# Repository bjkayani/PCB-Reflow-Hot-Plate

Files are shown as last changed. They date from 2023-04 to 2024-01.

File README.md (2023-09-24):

# PCB Reflow Hot Plate

The PCB Reflow Hot Plate is a temperature controlled 120 x 70 mm hot plate designed to reflow solder SMD circuit boards. This project was started due to a gap in the commercial solutions for a mid sized form factor hot plate. 

This project is a work in progress and various elements of it are continually improving and changing. Refer to the build guide for more information including a compatibility table. 

<br>

</a>

<br>

## Features

- 120x70mm (4.7x2.7in) aluminum hot plate
- 300 Watt PTC heating element
- ESP32-C3 based control board
- Tuned PID controller with configurable parameters
- Reflow mode with customizable reflow profiles
- Constant temeprature (heat) mode
- Upto 260 C temperature allows lead free reflow
- Easy to use GUI using 0.96" OLED display and 3 buttons
- Serial debugging over USB to monitor temperature
- Single power cable required for operation

<br>

## Design

### The main design considerations were:
- Atleast 70x70mm reflow area (the Miniware is 30x30mm)
- Slim design to allow tweezer manipulation with hands resting on the desk
- Commercially viable solution with a long operating life
- Easy to operature and minimal setup process
- Safe operation with multiple layers of safety

With these considerations in mind, this is the design I came up with. It uses an off the shelf heating plate with an embedded 300W heating element. I designed my own control board that includes everything needed to control the heating plate and can run entirely from mains input. 

I went with a small 0.96" OLED display and three buttons as that seems adequate to control the UI. The UI is simple and intuitive yet provides all the functionality needed to operate and customize the hot plate. 

Its all packaged in a slim, rectangular 3D printed case that exposes the hot plate provide a window for the display and integrated buttons. The hotplate has insulation placed underneath it to prevent heat loss from the bottom. The case needs to be printed in a relatively temperature resistant material to avoid warping at high temperature. 

</a>

<br>

## PCB

The PCB is designed in KiCAD. Its a 2-layer design and it contains everything needed to run the hot plate with a single mains input. The USB-C port provides power to the DC section and allows for programming the ESP32-C3 microcontroller. The OLED display is on a separate daughter board and mounted using M2 standoffs. A standard 0.96" OLED display module should work although there is some variation in the models avaiable. More information regarding that coming soon. 

### Version 1.1:

- [BOM](PCB/pcb-reflow-hot-plate/bom/pcb-reflow-hot-plate_1.2.html)
- [Gerber](PCB/pcb-reflow-hot-plate/output/pcb-reflow-hot-plate_Rev1.2.zip)

### Revision History

- Rev 1.0
    - Initial design
- Rev 1.1
    - AC-DC converter changed to HLK-5M05
    - SSR changed to popular OMRON compatible footprint
    - OLED display module moved to center align with buttons
    - SSR supply changed to +5V
    - AC in connector mounting peg holes increased in size
    - Minor silk screen updates
- Rev 1.2
    - AC in connector mounting holes further widened
    - OLED module footprint changed for newer modules
    - Tactile switches changed to 4.5x4.5x5mm
    - Neopixel added
    - Stemma QT connector added
    - SMD buzzer changed to SMD
    - AC fuse added
- Rev 1.3
    - RGB LED moved down
    - Heater and thermocouple connector rotated
    - Thermocouple GND line grounded

</a>
</a>

<br>

## Code

The code is written in Arduino IDE due to its ease of use and simlicity over PlatformIO and native ESP SDK. The code is split up into multiple files with each file containing functions relating to specific funcionality. 

The code is continually under development and I am adding new features regularly. I have also commented the code so that its easy to understand. Feel free to look through the code, file an issue if you encounter one or request features to be added. 

I have a lot of features I want to add that are on the road map but I first wanted to get the basic funtionality working and tested. These are listed at the start of the [main program file](Code/pcb-reflow-hot-plate/pcb-reflow-hot-plate.ino). 

<br>

## CAD

The housing is designed in SolidWorks. Its designed as a two part enclosure with a tab and screws to hold the two together. The heating plate comes with silicon feet that fit into the base. The base is raised to be slighly protruding from the top surface and insulation is put underneath to avoid heat dissipation from the bottom. 

The latest STL and design files can be found in the CAD folder. The assembly is missing the PCB due to import issues from KiCAD into SolidWorks.

</a>
</a>

<br>

## Build Guide

### Build guide is coming soon ...

### Compatibility Table

| PCB (HW) | OLED Module | Code (FW) | CAD |
| :---: | :---: | :---: | :---: |
| Rev 1.0 | SSD1306 0.96" 25.2x26mm <br> [AliExpress Link](https://www.aliexpress.us/item/2251832644208699.html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) | 1.0 | Housing Top v1 <br> Housing Base v1 |
| Rev 1.1 |  SSD1306 0.96" 27.6x27.6mm <br> [Amazon Link](https://amzn.to/43KL0ey) | 1.0  | Housing Top v2 <br> Housing Base v1 |
| Rev 1.2 |  SSD1306 0.96" 27.6x27.6mm <br> [Amazon Link](https://amzn.to/43KL0ey) | 1.1 |Housing Top v3 <br> Housing Base v2 <br> Light Pipe v1 |
| Rev 1.3 |  SSD1306 0.96" 27.6x27.6mm <br> [Amazon Link](https://amzn.to/43KL0ey) | 1.1 | Housing Top v3 <br> Housing Base v2 <br> Light Pipe v2 |

<br>

## Future Ideas
- [ ] Add mounting holes and pogo pin body connectors for accessories such as cooling fan, external temperature probe, fume extractor
- [ ] Make display separate from main PCB and shrink the main PCB
- [ ] Move the buttons to the bottom of the display
- [ ] Increase the size of the display to ~1.5in
- [ ] Switch to DC heater with thinner hot plate and USB-C PD (100 Watts)
- [ ] Switch to a square heating element
- [ ] Add integrated active cooling that blows air parallel to the hot plate
- [ ] Add multiple sensing options (thermocouple, thermistor etc.)
- [x] Add AC protection fuse
- [ ] Protection for reverse wired thermocouple

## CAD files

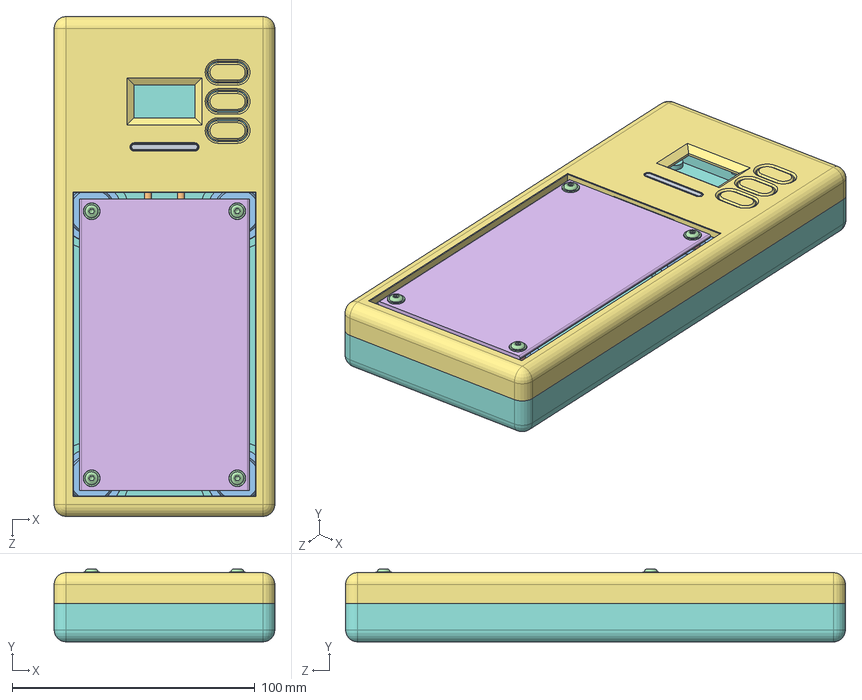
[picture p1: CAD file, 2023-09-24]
CAD/PCB Reflow Hot Plate Assembly.SLDASM
91.0 x 30.0 x 206.0 mm
Housing Base
Housing Top
hot-plate-120x70
M3-standoff x 4
97654A673_18-8 Stainless Steel Flanged Button Head Screw x 4
silicon-feet x 4
heating-element
light pipe

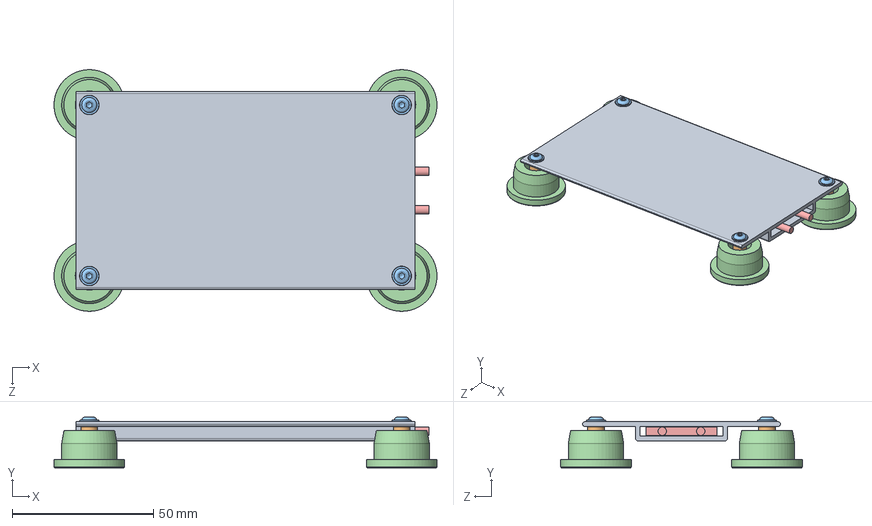
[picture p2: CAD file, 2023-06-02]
CAD/hot-plate-120x70-assembly.SLDASM
135.5 x 18.0 x 85.5 mm
hot-plate-120x70
M3-standoff x 4
97654A673_18-8 Stainless Steel Flanged Button Head Screw x 4
silicon-feet x 4
heating-element

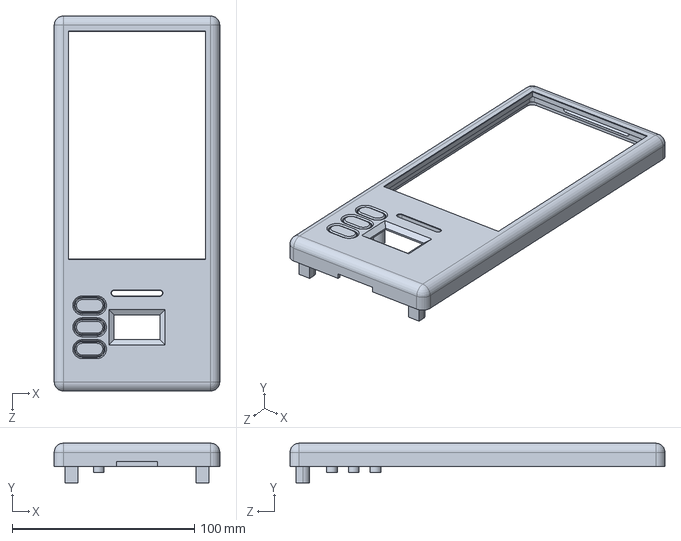
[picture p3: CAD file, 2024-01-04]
CAD/Housing Top.SLDPRT
91.0 x 21.8 x 206.0 mm

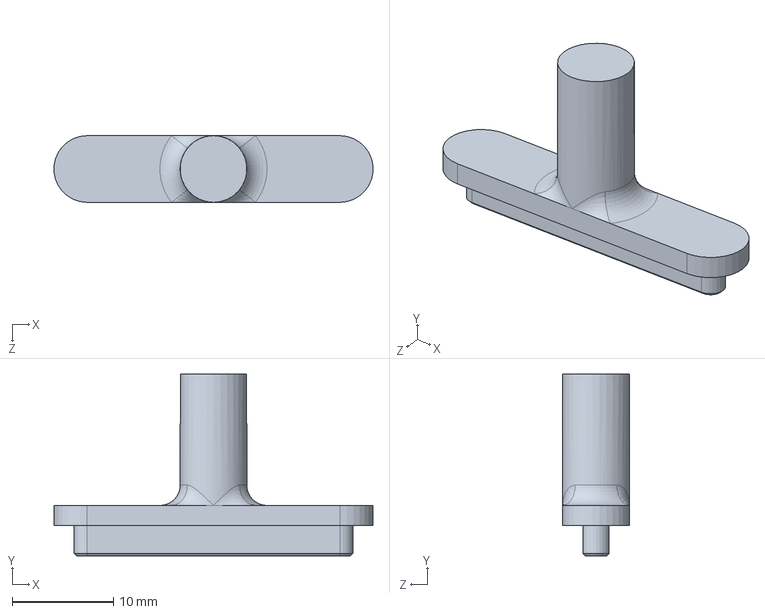
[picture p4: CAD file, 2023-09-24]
CAD/light pipe.SLDPRT
31.6 x 18.0 x 6.60 mm

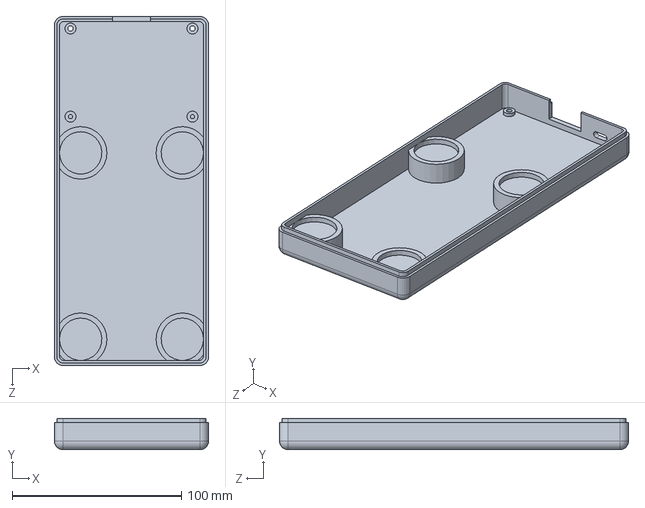
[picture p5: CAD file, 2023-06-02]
CAD/Housing Base.SLDPRT
91.0 x 18.5 x 206.0 mm

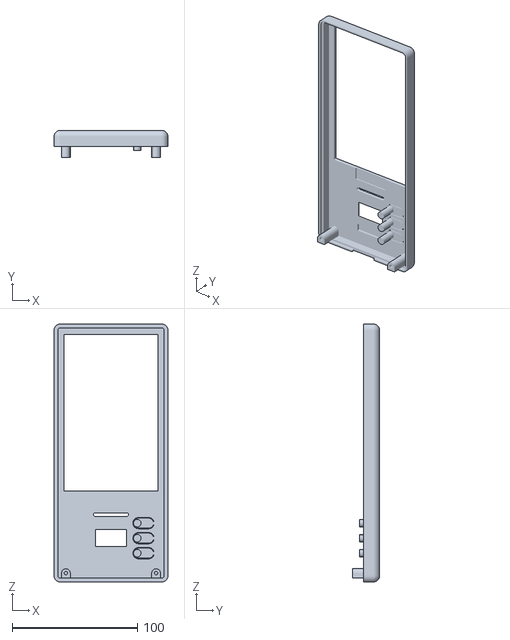
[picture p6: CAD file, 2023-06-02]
CAD/stl/Housing Top v3.STL
91.0 x 21.8 x 206.0

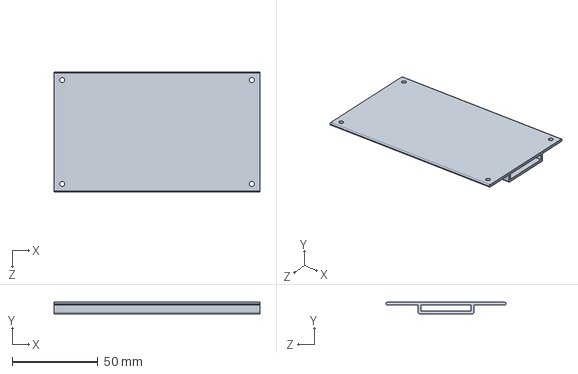
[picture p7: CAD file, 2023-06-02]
CAD/hot-plate-120x70.SLDPRT
120.0 x 6.76 x 70.0 mm

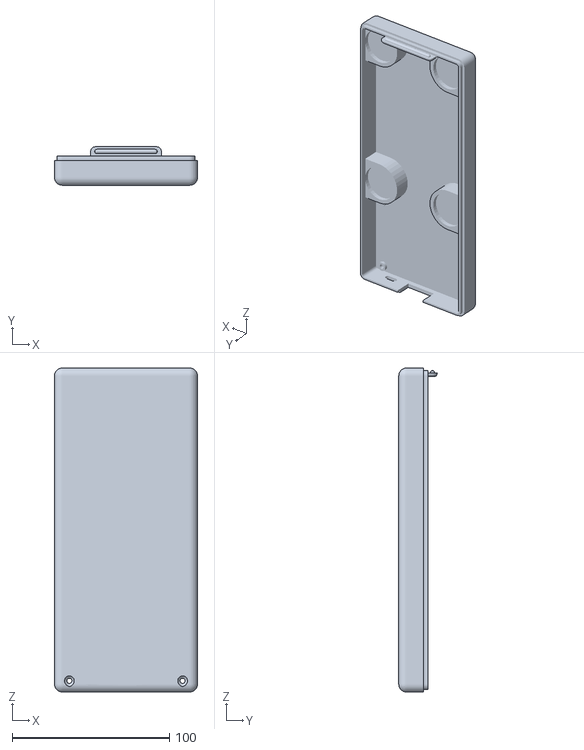
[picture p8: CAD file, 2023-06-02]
CAD/stl/Housing Base v2.STL
91.0 x 24.5 x 206.0

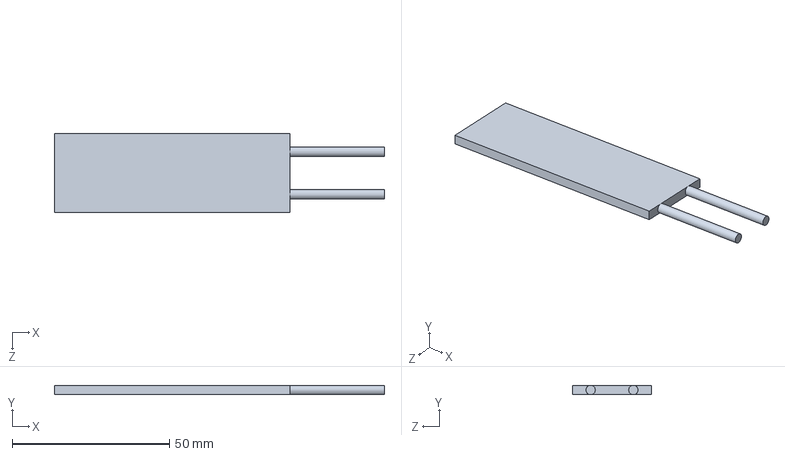
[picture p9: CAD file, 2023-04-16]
CAD/heating-element.SLDPRT
105.0 x 3.00 x 25.0 mm

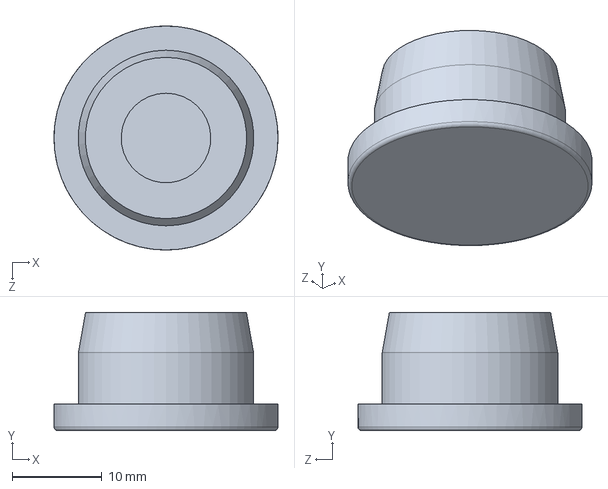
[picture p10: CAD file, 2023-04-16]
CAD/silicon-feet.SLDPRT
25.0 x 13.2 x 25.0 mm

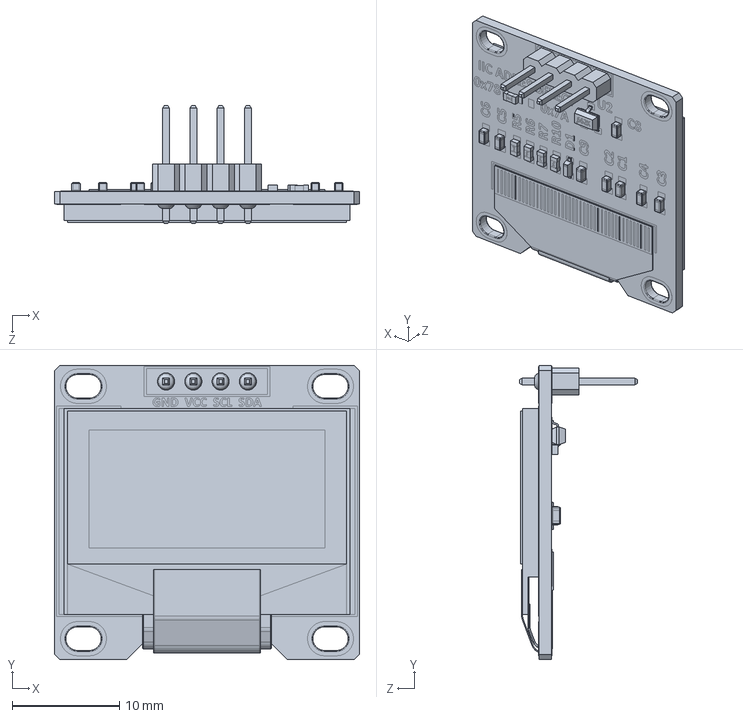
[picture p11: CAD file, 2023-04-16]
CAD/OLED 0.96'' 128x64.stp.SLDPRT
28.4 x 27.4 x 11.0 mm

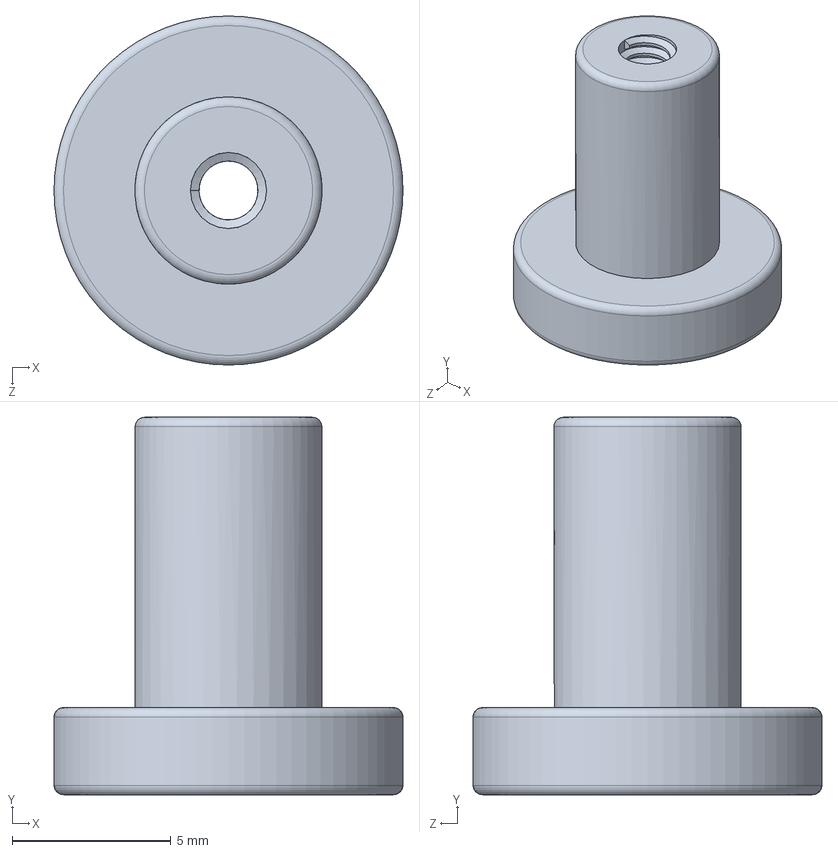
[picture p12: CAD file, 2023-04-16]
CAD/M3-standoff.SLDPRT
11.0 x 11.9 x 11.0 mm

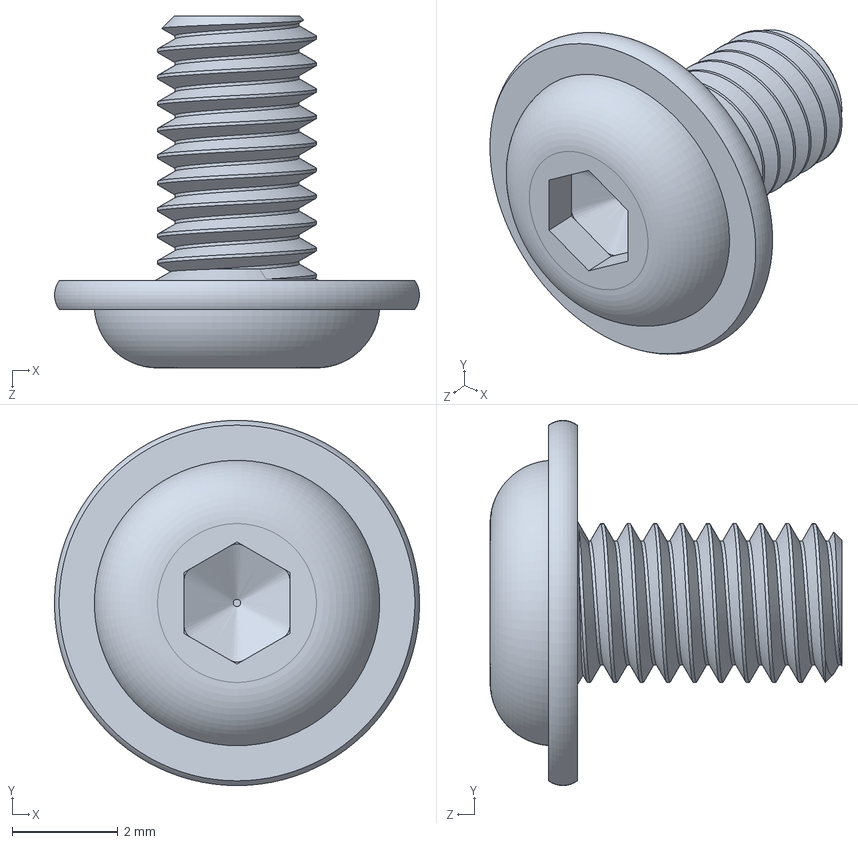
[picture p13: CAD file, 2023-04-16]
CAD/97654A673_18-8 Stainless Steel Flanged Button Head Screw.SLDPRT
6.90 x 6.90 x 6.65 mm

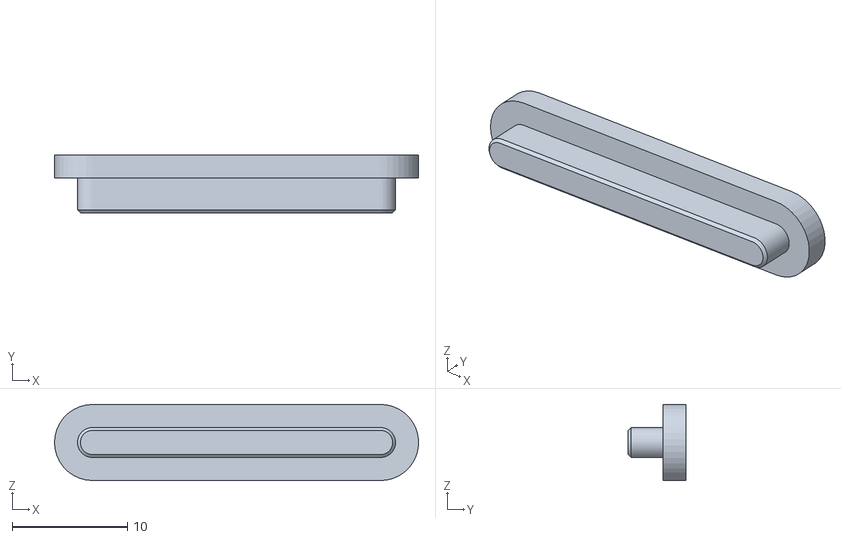
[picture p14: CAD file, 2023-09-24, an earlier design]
CAD/stl/light pipe v1.STL
31.6 x 5.00 x 6.60

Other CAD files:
CAD/stl/Housing Top v3-1.STL
CAD/stl/light pipe v2.STL
CAD/stl/Housing Top v2.STL
CAD/stl/Housing Top v1.STL
CAD/stl/Housing Base v1.STL

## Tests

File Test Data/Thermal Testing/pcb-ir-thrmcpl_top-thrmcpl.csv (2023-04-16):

Channel 1 | Channel 2 | Channel 3
0 | 0 | 0
0 | 0 | 0
0 | 0 | 0
0 | 0 | 0
0 | 0 | 0
0 | 0 | 0
0 | 0 | 0
0 | 0 | 0
0 | 0 | 0
0 | 0 | 0
0 | 0 | 0
0 | 0 | 0
0 | 0 | 0
0 | 0 | 0
0 | 0 | 0
0 | 0 | 0
0 | 0 | 0
0 | 0 | 0
0 | 0 | 0
0 | 0 | 0
0 | 0 | 0
0 | 0 | 0
0 | 0 | 0
0 | 0 | 0
0 | 0 | 0
0 | 0 | 0
0 | 0 | 0
0 | 0 | 0
0 | 0 | 0
0 | 0 | 0
0 | 0 | 0
0 | 0 | 0
0 | 0 | 0
0 | 0 | 0
0 | 0 | 0
0 | 0 | 0
0 | 0 | 0
0 | 0 | 0
0 | 0 | 0
0 | 0 | 0
0 | 0 | 0
0 | 0 | 0
0 | 0 | 0
0 | 0 | 0
0 | 0 | 0
0 | 0 | 0
0 | 0 | 0
0 | 0 | 0
0 | 0 | 0
0 | 0 | 0
0 | 0 | 0
0 | 0 | 0
0 | 0 | 0
0 | 0 | 0
0 | 0 | 0
0 | 0 | 0
0 | 0 | 0
0 | 0 | 0
0 | 0 | 0
0 | 0 | 0
0 | 0 | 0
0 | 0 | 0
0 | 0 | 0
0 | 0 | 0
0 | 0 | 0
0 | 0 | 0
0 | 0 | 0
0 | 0 | 0
0 | 0 | 0
0 | 0 | 0
0 | 0 | 0
0 | 0 | 0
0 | 0 | 0
0 | 0 | 0
0 | 0 | 0
0 | 0 | 0
0 | 0 | 0
0 | 0 | 0
0 | 0 | 0
0 | 0 | 0
0 | 0 | 0
0 | 0 | 0
0 | 0 | 0
0 | 0 | 0
0 | 0 | 0
0 | 0 | 0
0 | 0 | 0
0 | 0 | 0
0 | 0 | 0
0 | 0 | 0
0 | 0 | 0
0 | 0 | 0
0 | 0 | 0
0 | 0 | 0
0 | 0 | 0
0 | 0 | 0
0 | 0 | 0
0 | 0 | 0
0 | 0 | 0
0 | 0 | 0
0 | 0 | 0
0 | 0 | 0
0 | 0 | 0
0 | 0 | 0
0 | 0 | 0
0 | 0 | 0
0 | 0 | 0
0 | 0 | 0
0 | 0 | 0
0 | 0 | 0
0 | 0 | 0
0 | 0 | 0
0 | 0 | 0
0 | 0 | 0
0 | 0 | 0
0 | 0 | 0
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

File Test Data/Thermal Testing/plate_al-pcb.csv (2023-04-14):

Channel 1 | Channel 2
0 | 0
0 | 0
0 | 0
0 | 0
0 | 0
0 | 0
0 | 0
0 | 0
0 | 0
0 | 0
0 | 0
0 | 0
0 | 0
0 | 0
0 | 0
0 | 0
0 | 0
0 | 0
0 | 0
0 | 0
0 | 0
0 | 0
0 | 0
0 | 0
0 | 0
0 | 0
0 | 0
0 | 0
0 | 0
0 | 0
0 | 0
0 | 0
0 | 0
0 | 0
0 | 0
0 | 0
0 | 0
0 | 0
0 | 0
0 | 0
0 | 0
0 | 0
0 | 0
0 | 0
0 | 0
0 | 0
0 | 0
0 | 0
0 | 0
0 | 0
0 | 0
0 | 0
0 | 0
0 | 0
0 | 0
0 | 0
0 | 0
0 | 0
0 | 0
0 | 0
0 | 0
0 | 0
0 | 0
0 | 0
0 | 0
0 | 0
0 | 0
0 | 0
0 | 0
0 | 0
0 | 0
0 | 0
0 | 0
0 | 0
0 | 0
0 | 0
0 | 0
0 | 0
0 | 0
0 | 0
0 | 0
0 | 0
0 | 0
0 | 0
0 | 0
0 | 0
0 | 0
0 | 0
0 | 0
0 | 0
0 | 0
0 | 0
0 | 0
0 | 0
0 | 0
0 | 0
0 | 0
0 | 0
0 | 0
0 | 0
0 | 0
0 | 0
0 | 0
0 | 0
0 | 0
0 | 0
0 | 0
0 | 0
0 | 0
0 | 0
0 | 0
0 | 0
0 | 0
0 | 0
0 | 0
0 | 0
0 | 0
0 | 0
0 | 0
0 | 0
0 | 0
0 | 0
0 | 0
0 | 0
0 | 0
0 | 0
0 | 0
0 | 0
0 | 0
0 | 0
0 | 0
0 | 0
0 | 0
0 | 0
0 | 0
0 | 0
0 | 0
0 | 0
0 | 0
0 | 0
0 | 0
0 | 0
0 | 0
0 | 0
0 | 0
0 | 0
0 | 0
0 | 0
0 | 0
0 | 0
0 | 0
0 | 0
0 | 0
0 | 0
0 | 0
0 | 0
0 | 0
0 | 0
0 | 0
0 | 0
0 | 0
0 | 0
0 | 0
0 | 0
0 | 0
0 | 0
0 | 0
0 | 0
0 | 0
0 | 0
0 | 0
0 | 0
0 | 0
0 | 0
0 | 0
0 | 0
0 | 0
0 | 0
0 | 0
0 | 0
0 | 0
0 | 0
0 | 0
0 | 0
0 | 0
0 | 0
0 | 0
0 | 0
0 | 0
0 | 0
0 | 0
0 | 0
0 | 0
0 | 0
0 | 0
0 | 0
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

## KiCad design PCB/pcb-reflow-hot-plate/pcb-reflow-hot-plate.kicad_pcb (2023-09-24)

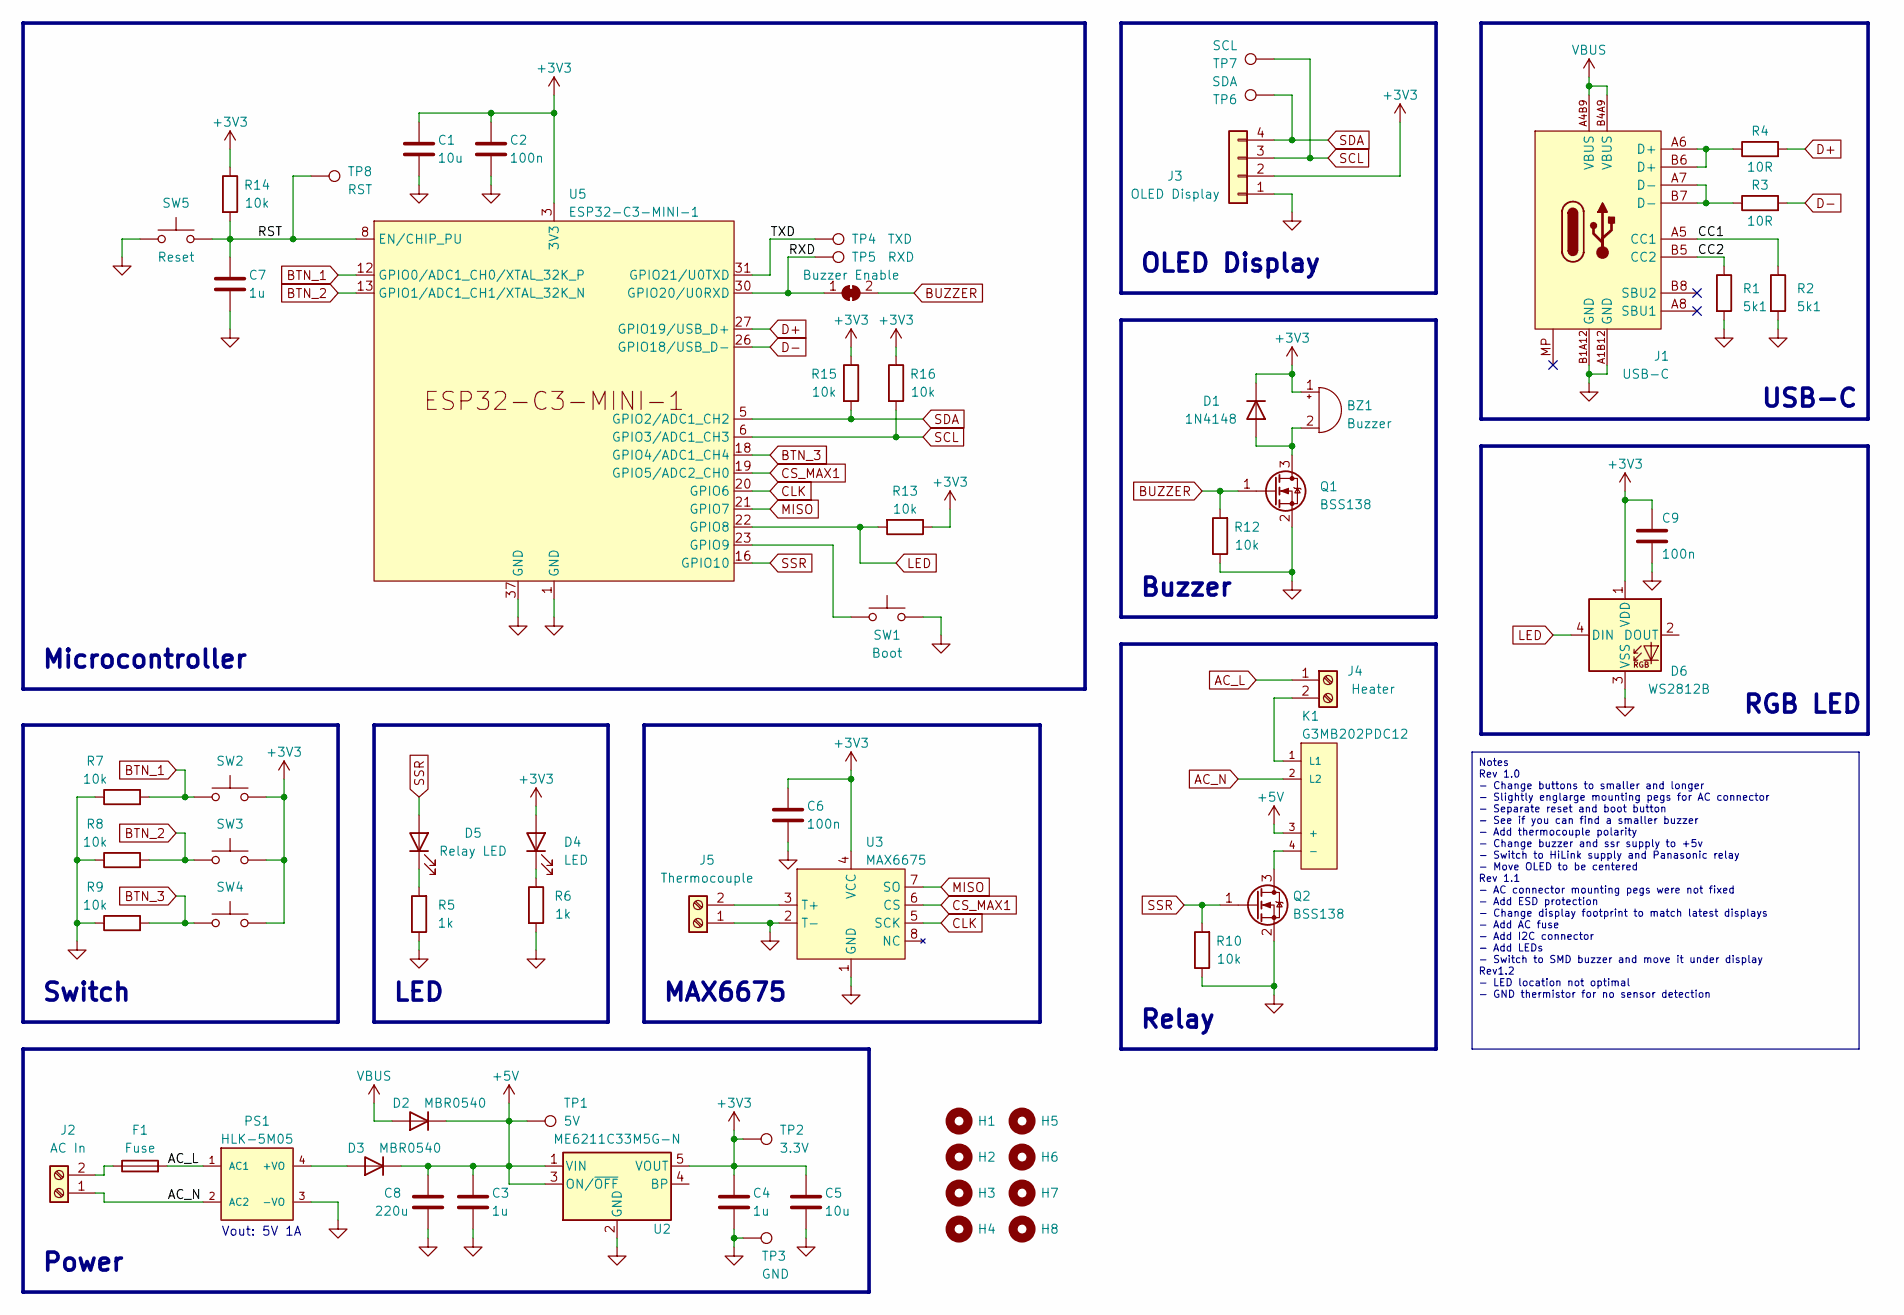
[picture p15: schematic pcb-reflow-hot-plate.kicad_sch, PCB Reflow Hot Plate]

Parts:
BZ1: Buzzer; CMI-9653S-SMT-TR; Part Number HNB09A03; LCSC Part Number C96102
C1, C5: 10u; C_0603_1608Metric; Part Number GRM188B30J106ME47D; LCSC Part Number C15499
C2, C6, C9: 100n; C_0402_1005Metric; Part Number GCM155R71C104KA40D; LCSC Part Number C126523
C3, C4, C7: 1u; C_0402_1005Metric; Part Number GRM155R61C105KE01D; LCSC Part Number C77007
C8: 220u; C_Elec_6.3x5.8; Part Number RST220UF10V018; LCSC Part Number C4747973
D1: 1N4148; D_SOD-123; Part Number 1N4148W-7-F; LCSC Part Number C83528
D2, D3: MBR0540; D_SOD-123; Part Number MBR0540; LCSC Part Number C77337
D4: LED; LED_0603_1608Metric; Part Number NCD0603G1; LCSC Part Number C84267
D5: Relay LED; LED_0603_1608Metric; Part Number NCD0603G1; LCSC Part Number C84267
D6: WS2812B; LED_WS2812B_PLCC4_5.0x5.0mm_P3.2mm; Part Number WS2812B-B/W; LCSC Part Number C114586
F1: Fuse; Fuse_Littelfuse_395Series; Part Number SQT3.15M; LCSC Part Number C312031
H1, H2, H3, H4: MountingHole; MountingHole_3.2mm_M3_Pad_Via
H5, H6, H7, H8: MountingHole; MountingHole_2.2mm_M2_Pad
J1: USB-C; Conn_USB-C_Receptacle_16Pin_Horizontal; Part Number TYPE-C 16PIN 2MD(073); LCSC Part Number C2765186
J2: AC In; Conn_IEC-C1_AC_Receptacle_2-Pin; Part Number RT-C08-F2-WH; LCSC Part Number C309250
J3: OLED Display; PinHeader_1x04_P2.54mm_Vertical; Part Number 2685Y-104CNG1SNA01; LCSC Part Number C350310
J4: Heater; TerminalBlock_RND_205-00001_1x02_P5.00mm_Horizontal; Part Number DB128V-5.0-2P-GN-S; LCSC Part Number C395860
J5: Thermocouple; TerminalBlock_4Ucon_1x02_P3.50mm_Horizontal; Part Number DB301V-3.5-2P-GN-S; LCSC Part Number C695629
JP1: Buzzer Enable; SolderJumper-2_P1.3mm_Bridged_RoundedPad1.0x1.5mm
K1: G3MB202PDC12; RELAY_G3MB202PDC12; Part Number AQG22205; LCSC Part Number C124000
PS1: HLK-5M05; CONV_HLK-5M05; Part Number HLK-5M05; LCSC Part Number C209907
Q1, Q2: BSS138; SOT-23; Part Number BSS138; LCSC Part Number C2874697
R1, R2: 5k1; R_0402_1005Metric; Part Number RC0402FR-075K1L; LCSC Part Number C105872
R3, R4: 10R; R_0402_1005Metric; Part Number RC0402FR-0710RL; LCSC Part Number C138066
R5, R6: 1k; R_0402_1005Metric; Part Number RC0603FR-071KL; LCSC Part Number C22548
R7, R8, R9, R10, R12, R13, R14, R15, R16: 10k; R_0402_1005Metric; Part Number RC0603FR-0710KL; LCSC Part Number C98220
SW1: Boot; GT-TC034F-H018-L1; Part Number GT-TC034F-H018-L1; LCSC Part Number C2835023
SW2, SW3, SW4: TL3305AF260QG; Part Number GT-TC074B-H050-L1; LCSC Part Number C843607
SW5: Reset; GT-TC034F-H018-L1; Part Number GT-TC034F-H018-L1; LCSC Part Number C2835023
TP1: 5V; TestPoint_Pad_D1.5mm
TP2: 3.3V; TestPoint_Pad_D1.5mm
TP3: GND; TestPoint_Pad_D1.5mm
TP4: TXD; TestPoint_Pad_D1.5mm
TP5: RXD; TestPoint_Pad_D1.5mm
TP6: SDA; TestPoint_Pad_D1.5mm
TP7: SCL; TestPoint_Pad_D1.5mm
TP8: RST; TestPoint_Pad_D1.5mm
U2: ME6211C33M5G-N; SOT-23-5; Part Number ME6211C33M5G-N; LCSC Part Number C82942
U3: MAX6675; SOIC-8_3.9x4.9mm_P1.27mm; Part Number MAX6675ISA+T; LCSC Part Number C16030
U5: ESP32-C3-MINI-1; Part Number ESP32-C3-MINI-1-N4; LCSC Part Number C5290152

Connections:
+3V3: BZ1.1 (-), C1.1, C2.1, C4.1, C5.1, C6.1, C9.1, D1.1 (K), D4.2 (A), D6.1 (VDD), J3.2, R13.1, R14.1, R15.1, R16.1, SW2.2, SW3.2, SW4.2, TP2.1, U2.5 (VOUT), U3.4 (VCC), U5.3 (3V3)
+5V: C3.1, C8.1, D2.1 (K), D3.1 (K), K1.3 (+), TP1.1, U2.1 (VIN), U2.3 (ON/~OFF)
/CC1: J1.A5 (CC1), R2.1
/CC2: J1.B5 (CC2), R1.1
/RST: C7.1, R14.2, SW5.2, TP8.1, U5.8 (EN/CHIP_PU)
/RXD: JP1.1 (A), TP5.1, U5.30 (GPIO20/U0RXD)
/TXD: TP4.1, U5.31 (GPIO21/U0TXD)
AC_L: F1.2, J4.1, PS1.1 (AC1)
AC_N: J2.1, K1.2 (L2), PS1.2 (AC2)
BTN_1: R7.2, SW2.1, U5.12 (GPIO0/ADC1_CH0/XTAL_32K_P)
BTN_2: R8.2, SW3.1, U5.13 (GPIO1/ADC1_CH1/XTAL_32K_N)
BTN_3: R9.2, SW4.1, U5.18 (GPIO4/ADC1_CH4)
BUZZER: JP1.2 (B), Q1.1 (G), R12.2
CLK: U3.5 (SCK), U5.20 (GPIO6)
CS_MAX1: U3.6 (CS), U5.19 (GPIO5/ADC2_CH0)
D+: R4.2, U5.27 (GPIO19/USB_D+)
D-: R3.2, U5.26 (GPIO18/USB_D-)
GND: C1.2, C2.2, C3.2, C4.2, C5.2, C6.2, C7.2, C8.2, C9.2, D6.3 (VSS), J1.A1B12 (GND), J1.B1A12 (GND), J3.1, J5.1, PS1.3 (-VO), Q1.2 (S), Q2.2 (S), R1.2, R2.2, R5.1, R6.2, R7.1, R8.1, R9.1, R10.1, R12.1, SW1.2, SW5.1, TP3.1, U2.2 (GND), U3.1 (GND), U3.2 (T-), U5.1 (GND), U5.2 (GND), U5.11 (GND), U5.14 (GND), U5.36 (GND), U5.37 (GND), U5.38 (GND), U5.39 (GND), U5.40 (GND), U5.41 (GND), U5.42 (GND), U5.43 (GND), U5.44 (GND), U5.45 (GND), U5.46 (GND), U5.47 (GND), U5.48 (GND), U5.49 (GND), U5.50 (GND), U5.51 (GND), U5.52 (GND), U5.53 (GND)
LED: D6.4 (DIN), R13.2, U5.22 (GPIO8)
MISO: U3.7 (SO), U5.21 (GPIO7)
unnamed: BZ1.2 (+), D1.2 (A), Q1.3 (D)
unnamed: D3.2 (A), PS1.4 (+VO)
unnamed: D4.1 (K), R6.1
unnamed: D5.1 (K), R5.2
unnamed: J1.A6 (D+), J1.B6 (D+), R4.1
unnamed: J1.A7 (D-), J1.B7 (D-), R3.1
unnamed: F1.1, J2.2
unnamed: J4.2, K1.1 (L1)
unnamed: J5.2, U3.3 (T+)
unnamed: K1.4 (-), Q2.3 (D)
unnamed: SW1.1, U5.23 (GPIO9)
SCL: J3.3, R16.2, TP7.1, U5.6 (GPIO3/ADC1_CH3)
SDA: J3.4, R15.2, TP6.1, U5.5 (GPIO2/ADC1_CH2)
SSR: D5.2 (A), Q2.1 (G), R10.2, U5.16 (GPIO10)
VBUS: D2.2 (A), J1.A4B9 (VBUS), J1.B4A9 (VBUS)

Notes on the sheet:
Notes Rev 1.0 - Change buttons to smaller and longer - Slightly englarge mounting pegs for AC connector - Separate reset and boot button - See if you can find a smaller buzzer - Add thermocouple polarity - Change buzzer and ssr supply to +5v - Switch to HiLink supply and Panasonic relay - Move OLED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
LED
USB-C
RGB LED
Power
Relay
Switch
MAX6675
Vout: 5V 1A
Microcontroller
Buzzer
OLED Display

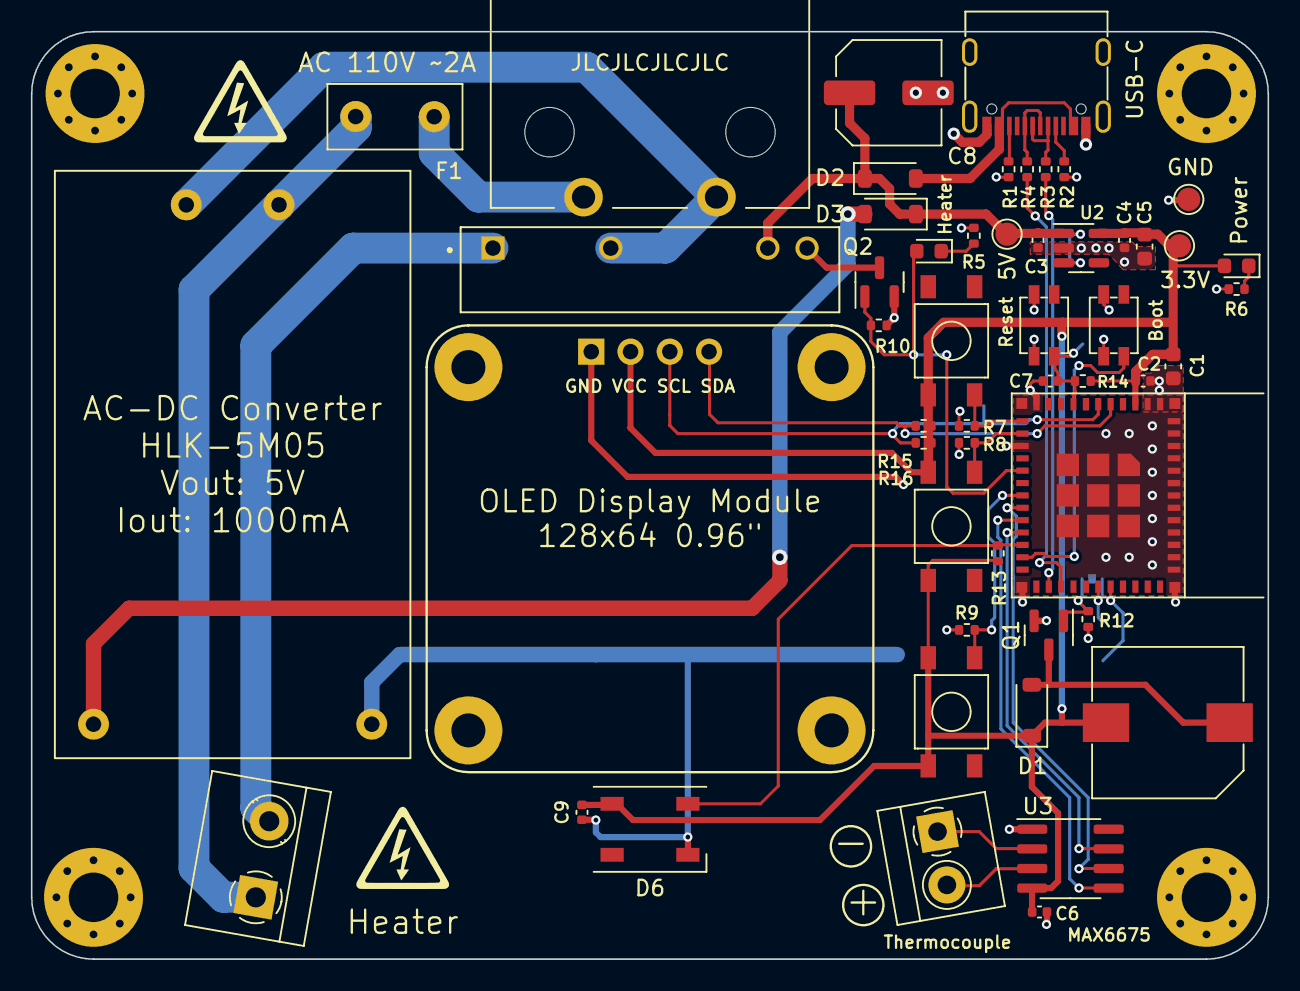
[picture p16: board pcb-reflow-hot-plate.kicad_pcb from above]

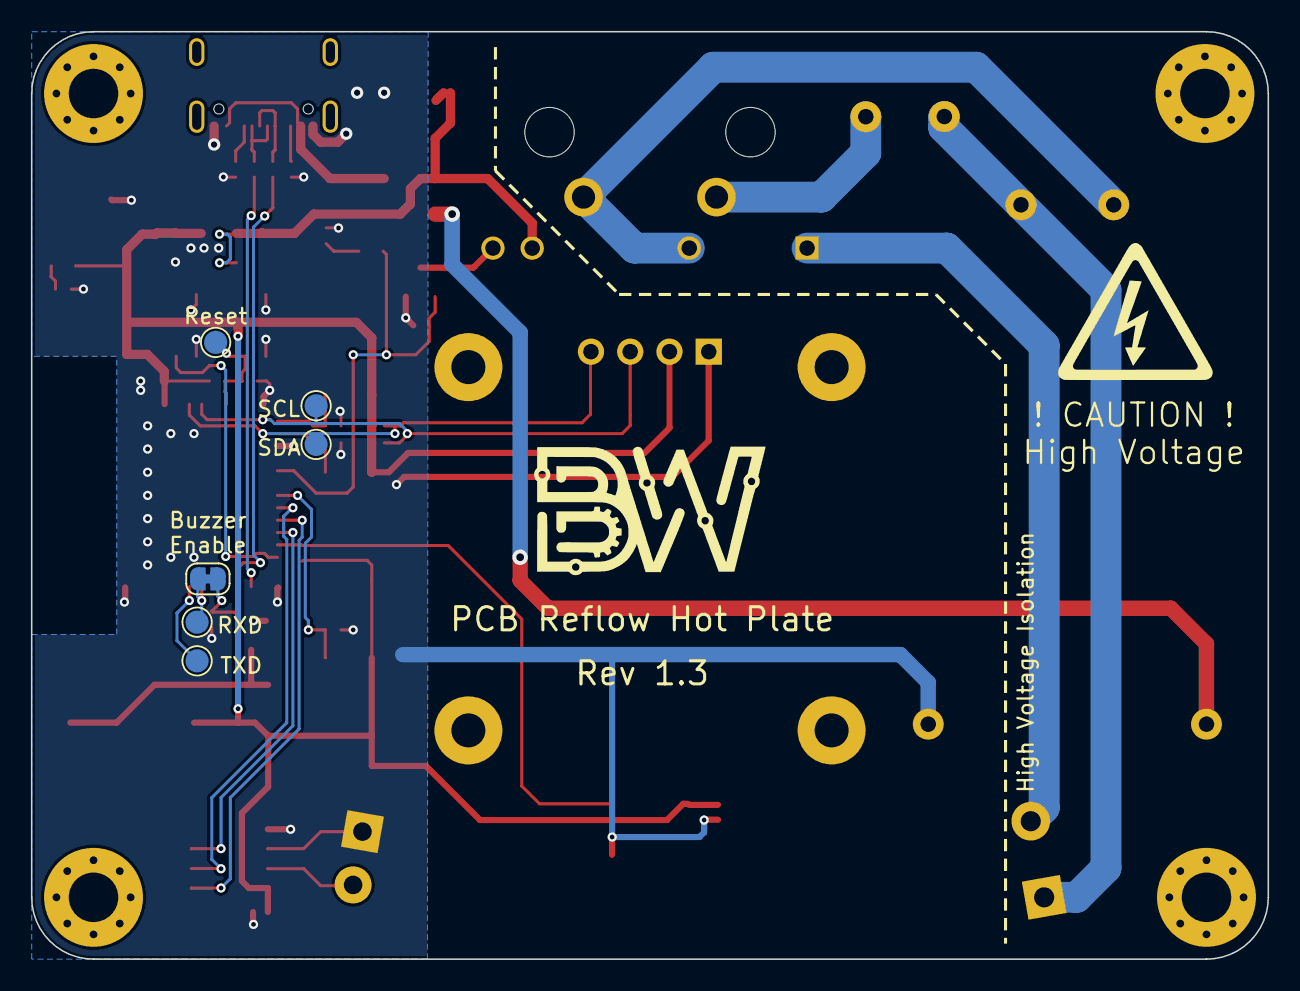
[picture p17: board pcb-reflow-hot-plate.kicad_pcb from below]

Board: 2 copper layers, 80.0 x 60.0 mm, 66 parts (6 on the bottom side), 35 nets.

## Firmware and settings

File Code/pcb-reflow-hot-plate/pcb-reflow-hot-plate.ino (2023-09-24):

/**
  * PCB Reflow Hot Plate
  * Author: Badar Jahangir Kayani
  * Email: badarjahangir@gmail.com
  * Date: 4/10/2023
  * Platform: ESP32-C3-MINI-1-N4 base custom PCB
  * 
  * TODO:
  *   - Add WiFi support with configuration options
  *   - Add BLE support with configuration options
  *   - Add status icons for WiFi and BLE
  *   - Add option to print variables over serial
  *   - Settings menu: ( WiFi, BLE, USB Serial)
  *   - Add multiple temp sensor support
  *   - Add usb plug in/mode detection
  *   - Add timed pop-up alert support
  *   - Add scroll bar for all menus
  *   - Add option to change profile name
  */


#include "MAX6675.h"
#include <Wire.h>
#include <Adafruit_GFX.h>
#include <Adafruit_SSD1306.h>
#include "HWCDC.h"
#include <Preferences.h>
#include <U8g2_for_Adafruit_GFX.h>
#include <WiFi.h>
#include <Adafruit_NeoPixel.h>

// ---------- IO Pin Definitions ----------

#define UP_BTN_PIN  0
#define OK_BTN_PIN  1
#define DN_BTN_PIN  4
#define BUZZER_PIN  20
#define SSR_PIN     10
#define SDA_PIN     2 // OLED Display
#define SCL_PIN     3 // OLED Display
#define DATA_PIN    7 // MAX6675
#define CLOCK_PIN   6 // MAX6675
#define SELECT_PIN  5 // MAX6675
#define RGB_LED_PIN 8

// ---------- Macros ----------

#define FW_VERSION            1.1
#define HW_VERSION            1.2
// Oled
#define OLED_SCREEN_ADDRESS   0x3C // I2C address
#define OLED_PIXEL_X          128
#define OLED_PIXEL_Y          64
// Button debounce
#define BUTTON_DEBOUNCE_TIME  20 // in mS
#define BUTTON_PRESS_TIME     100
// Temperature
#define TEMP_FILTER_WINDOW    10 // temp moving average window size
#define TEMP_UPDATE_INTERVAL  500 // temperature read interval in mS
#define MIN_TEMP              30
#define MAX_TEMP              260
#define SAFE_TEMP             70
// Setting change steps
#define SET_TEMP_STEP         5
#define PID_PARAMETER_STEP    0.1
#define REFLOW_TIME_STEP      10
#define REFLOW_TEMP_STEP      10
// SSR Relay PWM
#define PWM_FREQ              1 // in Hertz
#define PWM_PERIOD            (1000*(1/PWM_FREQ)) // Period in ms
#define PWM_MAX               100 // value for 100% PWM duty cycle
// Reflow profile
#define NUM_PROFILE_MAX       5 // stored profile capacity
#define PROFILE_MAX_POINTS    9  // time:Temperature point in each profile
// PID
#define PID_KD_PREGAIN        10.0
#define INTEG_ACTIVE_THRESH   80  // integral calc threshold to prevent windup
#define PID_FILTER_SIZE       10 // pid moving average window size
#define PID_STEP_INTERVAL     250 // PID update interval in mS
#define DERIV_CALC_INTERVAL   1000 // derivative calc interval for smoother response
// Buzzer
#define CLICK_BEEP            50   
#define SCROLL_BEEP           20
#define SCROLL_LIMIT_BEEP     100
#define START_UP_BEEP         200 
// Misc
#define MAX_REFLOW_TIME_S     600
#define NUM_SETTING_MAX       20
#define START_UP_SPLASH_TIME  2000
#define MAX_DISPLAY_LENGTH    20 
#define LED_BRIGHTNESS        150
// Error checking
#define BUFFER_TIME               30 // buffer time in seconds
#define BUFFER_SIZE               ((BUFFER_TIME * 1000) / ERROR_CHECK_INTERVAL)
#define ERROR_CHECK_INTERVAL      1000  // error checking interval in mS
#define HEAT_UP_MIN_TEMP_RISE     10  // minimal expected temp rise in BUFFER_TIME
#define HEAT_UP_CHECK_TEMP_LIMIT  200
#define HIGHTEMP_ERROR_LIMIT      280

// Switch between standard serial and usb serial
#define USB_DEBUG
#ifdef UART_DEBUG
  #define debugprint(x) Serial.print(x);
  #define debugprintln(x) Serial.println(x);
#endif
#ifdef USB_DEBUG
  #define debugprint(x) if(USBSerial.availableForWrite()){USBSerial.print(x);}
  #define debugprintln(x) if(USBSerial.availableForWrite()){USBSerial.println(x);}
#endif
#ifdef NO_DEBUG 
  #define debugprint(x)
  #define debugprintln(x)
#endif

// ---------- Objects ----------

MAX6675 thermoCouple;
Adafruit_SSD1306 display(OLED_PIXEL_X, OLED_PIXEL_Y, &Wire, -1);
Preferences preferences;
U8G2_FOR_ADAFRUIT_GFX u8g2_for_adafruit_gfx;
Adafruit_NeoPixel pixels(1, RGB_LED_PIN, NEO_GRB + NEO_KHZ800);

// ---------- Enums and Structs ----------

enum main_select_t{
  MAIN_REFLOW = 0,
  MAIN_HEAT,
  MAIN_PARAM,
  MAIN_SETTINGS,
  MAIN_ABOUT,

  MAIN_NUM_ITEMS
};

enum parameter_select_t{
  PARAMETER_PID = 0,
  PARAMETER_REFLOW,

  PARAMETER_NUM_ITEMS
};

enum pid_select_t{
  PID_KP = 0,
  PID_KI,
  PID_KD,
  PID_KP_R,
  PID_KI_R,
  PID_KD_R,

  PID_NUM_ITEMS
};

enum reflow_select_t{
  REFLOW_TIME = 0,
  REFLOW_TEMP,

  REFLOW_NUM_ITEMS
};

enum single_button_state_t {
  BUTTON_RELEASED = 0,
  BUTTON_PRESSED = 1,
  BUTTON_NO_ACTION
};

enum buttons_state_t {
  BUTTONS_NO_PRESS,
  BUTTONS_UP_PRESS,
  BUTTONS_OK_PRESS,
  BUTTONS_DN_PRESS,
  BUTTONS_UPDN_PRESS
};

enum settings_state_t {
  SETTINGS_BUZZER = 0,
  SETTINGS_RESET,
  SETTINGS_TIMEOUT,
  
  SETTINGS_NUM_ITEMS  
};

enum op_mode_t {
  REFLOW = 0,
  HEAT
};

enum color_t {
    RED,
    GREEN,
    BLUE
};

/**
 * Struct to save reflow profiles
 * Point of change in the profile will be saved
 * Each point is saved as a time/temp pair
 * Time steps should be chronological until max time
 * Time steps subsequent from max time can be zero
 */
struct reflow_profile_t{
  int time_steps[PROFILE_MAX_POINTS];
  int temp_steps[PROFILE_MAX_POINTS];
  char display_name[MAX_DISPLAY_LENGTH];
};

struct pid_item_t{
  char display_name[MAX_DISPLAY_LENGTH];
  float val;
};

// Struct to store information for settings menu
struct settings_item_t{
  char display_name[MAX_DISPLAY_LENGTH]; // display name for the setting
  char display_options[NUM_SETTING_MAX][MAX_DISPLAY_LENGTH];  // display strings for each option
  int values[NUM_SETTING_MAX]; // integer value associated with each option
  int num_options;  // total number of options
  int set_value_index; // the currently selected option index
};

// Struct to store a buzzer tone sequence
struct buzzer_sequence_t{
  int buzzer_on_time; // time in ms for buzzer to be on
  int buzzer_off_time;  // time in ms for buzzer to be off
  int num_of_beeps; // number of times to play the on-off sequence
  bool enable_bypass; // play regradless of buzzer being disabled
};

// ---------- Constants ----------

const reflow_profile_t leaded_profile = { {0, 100, 200, 260, 280, 500, 0, 0, 0},
                                          {50, 150, 150, 220, 220, 50, 0, 0, 0},             
                                          "Leaded" };

// Reflow graph constants
const int graph_temp_min = 40;
const int graph_temp_max = 240;
const int graph_width = 100;
const int graph_height = 40;
const int graph_x_origin = 14;
const int graph_y_origin = 0;
const int left_tick_perc_array[4] = {20, 40, 60, 80};

// ---------- Variables ----------

// Buttons
volatile single_button_state_t up_button_state = BUTTON_NO_ACTION;
volatile single_button_state_t ok_button_state = BUTTON_NO_ACTION;
volatile single_button_state_t dn_button_state = BUTTON_NO_ACTION;
volatile unsigned long up_state_change_time = 0;
volatile unsigned long ok_state_change_time = 0;
volatile unsigned long dn_state_change_time = 0;
// System
float cur_temp = 30;
int heater_pwm = 0;
// Reflow
bool reflow_active = false;
int selected_profile = 0; 
bool reflow_done = false;
bool reflow_paused = false;
int reflow_duration_s = 0;
// Heat
bool heat_active = false;
float heat_set_temp = 0.0;
// Graph
int graph_time_min = 0;
int graph_time_max = 400;
// Buzzer
unsigned long buzzer_on_time = 0;
int current_buzzer_duration = 0;
bool buzzer_on = false;
buzzer_sequence_t cur_buzzer_seq;
bool buzzer_seq_on = false;
unsigned long buzzer_seq_on_time = 0;
int buzzer_seq_index = 1;
// Errors
bool high_temp_error = false;
bool heat_up_error = false;
// Circular buffer
float temp_buffer[BUFFER_SIZE];
int pwm_buffer[BUFFER_SIZE];
int buffer_head = 0;
int buffer_tail = 0;
int buffer_count = 0;

char print_buffer[20];

String mac_address; // unique hardware address

reflow_profile_t reflow_profile_array[NUM_PROFILE_MAX];    

// Should match main_select_t
char main_items [MAIN_NUM_ITEMS] [MAX_DISPLAY_LENGTH] = {
  "Reflow",
  "Heat",
  "Parameters",
  "Settings",
  "About"
};

// Should match parameter_select_t
char parameter_items[PARAMETER_NUM_ITEMS][MAX_DISPLAY_LENGTH] = {
  "PID",
  "Profile"
};

// Should match pid_select_t
pid_item_t pid_items[PID_NUM_ITEMS] = {
  {"Kp", 8.0},
  {"Ki", 0.3},
  {"Kd", 4.5},
  {"Kp_r", 8.0},
  {"Ki_r", 0.6},
  {"Kd_r", 3.5}
};

settings_item_t setting_items[SETTINGS_NUM_ITEMS] = {
  {"Buzzer",  {"On", "Off"},  {1, 0}, 2, 0},
  {"Reset",   {"", "Sure? ^"}, {0, 1}, 2, 0},
  {"Timeout", {"10m", "9m", "8m", "7m", "6m", "5m"}, {600, 540, 480, 420, 360, 300}, 6, 0}
};

int heat_timeout = setting_items[SETTINGS_TIMEOUT].values[setting_items[SETTINGS_TIMEOUT].set_value_index];

const buzzer_sequence_t buzzer_timeout_seq = {200, 200, 2, true};
const buzzer_sequence_t buzzer_reflow_complete_seq = {200, 200, 2, true};
const buzzer_sequence_t buzzer_high_temp_error_seq = {500, 500, 50, true};
const buzzer_sequence_t buzzer_heat_up_error_seq = {200, 200, 10, true};

// ---------- Control Functions ----------

/**
 * @brief Main menu control function
 */
void mainMenu(){

  static int select_index = 0;

  while(1){
    buttons_state_t cur_button = getButtonsState();

    /** 
    * Main menu button control
    * 
    * UP/DN   scroll the menu
    * OK      select the highlighted option
    */  
    switch(cur_button){
      case BUTTONS_UP_PRESS:
        if(--select_index < 0){
          select_index = 0;
          buzzerBeep(SCROLL_LIMIT_BEEP);
        } else {
          buzzerBeep(SCROLL_BEEP);
        }
        break;
      case BUTTONS_DN_PRESS:
        if(++select_index >= MAIN_NUM_ITEMS){
          select_index = MAIN_NUM_ITEMS - 1;
          buzzerBeep(SCROLL_LIMIT_BEEP);
        } else {
          buzzerBeep(SCROLL_BEEP);
        }
        break;
      case BUTTONS_OK_PRESS:
        buzzerBeepBlocking(CLICK_BEEP);
        switch(select_index){
          case MAIN_REFLOW:
            reflow();
            break;
          case MAIN_HEAT:
            heat();
            break;
          case MAIN_PARAM:
            parameterMenu();
            break;
          case MAIN_SETTINGS:
            settings();
            break;
          case MAIN_ABOUT:
            about();
            break;
          default:
            break;
        }
        break;
      default:
        break;
    }

    showMainMenu(select_index);
    buzzerLoop();
    ledSetColor(BLUE, LED_BRIGHTNESS);
  }

}

/**
 * @brief Reflow control function
 * This mode runs predefined reflow profiles
 */
void reflow(){

  static unsigned int reflow_time_ms = 0;
  static unsigned int reflow_time_s = 0;
  static unsigned int reflow_pre_pause_time_ms = 0;
  static unsigned long reflow_on_time = 0;
  static unsigned int reflow_progress = 0; // percentage completed
  static float reflow_set_temp = 0.0;

  while(1){
    cur_temp = readTempSensor();
    buttons_state_t cur_button = getButtonsState();
    reflow_duration_s = getReflowMaxTime();

    // Enter if reflow is actively running
    if(reflow_active && !reflow_paused && !high_temp_error){
      reflow_time_ms = (millis() - reflow_on_time) + reflow_pre_pause_time_ms; // get time elapsed 
      reflow_time_s = reflow_time_ms / 1000;
      reflow_progress = (reflow_time_s * 100) / reflow_duration_s;
      // Get the target temp from profile, run the pid step and set heater PWM
      reflow_set_temp = getReflowTemp(reflow_profile_array[selected_profile], reflow_time_s);
      heater_pwm = pidStep(reflow_set_temp, REFLOW);
    }

    // Enter if reflow is completed
    if(reflow_active && reflow_progress >= 100){
      reflow_done = true;  
      reflow_active = false; 
      heater_pwm = 0;
      buzzerSeq(buzzer_reflow_complete_seq);
      debugprintln("reflow completed"); 
    }

    // Handle high temperature error
    if(high_temp_error && reflow_active){
      reflow_active = false;
      heater_pwm = 0;
      buzzerSeq(buzzer_high_temp_error_seq);  
    }

    // Handle heater error
    if(heat_up_error && reflow_active){
      reflow_active = false;
      heater_pwm = 0;
      buzzerSeq(buzzer_heat_up_error_seq); 
    }

    /** 
    * Reflow button control
    * 
    * UP/DN   change reflow profile selected
    * OK      start/pause/resume reflow
    * UP+DN   stop reflow and exit
    */        
    switch(cur_button){
      case BUTTONS_UP_PRESS:
        if(!reflow_active && !reflow_done && !heat_up_error && !high_temp_error){
          if(--selected_profile < 0){
            selected_profile = 0;
            buzzerBeep(SCROLL_LIMIT_BEEP);
          } else {
            buzzerBeep(SCROLL_BEEP);
          }
          updateMiscParams();
        }
        break;
      case BUTTONS_DN_PRESS:
        if(!reflow_active && !reflow_done && !heat_up_error && !high_temp_error){
          if(++selected_profile >= NUM_PROFILE_MAX){
            selected_profile = NUM_PROFILE_MAX - 1;
            buzzerBeep(SCROLL_LIMIT_BEEP);
          } else {
            buzzerBeep(SCROLL_BEEP);
          } 
          updateMiscParams();
        }
        break;
      case BUTTONS_OK_PRESS:
        buzzerBeep(CLICK_BEEP);
        if(reflow_active && !reflow_paused) { // pause reflow if its running
          reflow_paused = true;
          reflow_pre_pause_time_ms = reflow_time_ms;
          heater_pwm = 0;
          debugprintln("reflow paused");
        } else if (reflow_active && reflow_paused){ // resume reflow if paused
          reflow_paused = false; 
          reflow_on_time = millis();
        } else if (!reflow_done && !heat_up_error && !high_temp_error) {  // start reflow
          reflow_active = true;
          reflow_on_time = millis();
          reflow_time_s = 0;
          reflow_done = false;
          reflow_pre_pause_time_ms = 0;
          reflow_progress = 0;
          debugprintln("reflow started");
        }
        break;
      default:
        break;
    }

    // Reset reflow tracking variables and exit from reflow mode
    if(cur_button == BUTTONS_UPDN_PRESS){
      reflow_active = false;
      reflow_paused = false;
      reflow_done = false;
      high_temp_error = false;
      heat_up_error = false;
      reflow_progress = 0;
      heater_pwm = 0;
      heaterPwmLoop();  // called to set PWM before exiting
      debugprintln("reflow stopped");
      break;
    } 

    showReflow(reflow_set_temp, reflow_time_s, reflow_progress);
    buzzerLoop();
    errorCheckLoop(reflow_set_temp, reflow_active);
    heaterPwmLoop();
    ledHeatDisplay(cur_temp, LED_BRIGHTNESS);
  }
}

/**
 * @brief Heat mode control function
 * This mode heats the plate to a static temperature
 */
void heat(){

  static unsigned int heat_time_ms = 0;
  static unsigned int heat_time_s = 0;
  static unsigned long heat_on_time = 0;

  while(1){
    cur_temp = readTempSensor();
    buttons_state_t cur_button = getButtonsState();

    // Enter if heating has been turned on by the user
    if(heat_active){
      heat_time_ms = millis() - heat_on_time;
      heat_time_s = heat_time_ms / 1000;
      // Run the PID step and set heater PWM
      heater_pwm = pidStep(heat_set_temp, HEAT);
    }

    // Heating timed out
    if(heat_time_s > heat_timeout && heat_active){
      heat_active = false;
      heater_pwm = 0;
      buzzerSeq(buzzer_timeout_seq);
    }

    // Handle high temperature error
    if(high_temp_error && heat_active){
      heat_active = false;
      heater_pwm = 0;
      buzzerSeq(buzzer_high_temp_error_seq);  
    }

    // Handle heater error
    if(heat_up_error && heat_active){
      heat_active = false;
      heater_pwm = 0;
      buzzerSeq(buzzer_heat_up_error_seq); 
    }

    /** 
    * Heat button control
    * 
    * UP/DN   change heat set temperature
    * OK      start/stop heating
    * UP+DN   stop heating and exit
    */  
    switch(cur_button){
      case BUTTONS_UP_PRESS:
        heat_set_temp += SET_TEMP_STEP;
        if(heat_set_temp > MAX_TEMP){
          heat_set_temp = MAX_TEMP;
          buzzerBeep(SCROLL_LIMIT_BEEP);
        } else {
          buzzerBeep(SCROLL_BEEP);
        }
        updateMiscParams();
        break;
      case BUTTONS_DN_PRESS:
        heat_set_temp -= SET_TEMP_STEP;
        if(heat_set_temp < MIN_TEMP){
          heat_set_temp = MIN_TEMP;
          buzzerBeep(SCROLL_LIMIT_BEEP);
        } else {
          buzzerBeep(SCROLL_BEEP);
        }
        updateMiscParams();
        break;
      case BUTTONS_OK_PRESS:
        buzzerBeep(CLICK_BEEP);
        if(heat_active) {
          heat_active = false;
          heater_pwm = 0;
          debugprintln("heating stopped");
        } else if (!heat_up_error && !high_temp_error) {
          heat_active = true;
          heat_on_time = millis();
          debugprintln("heating started");
        }
        break;
      default:
        break;
    }

    if(cur_button == BUTTONS_UPDN_PRESS){
      heat_active = false;
      high_temp_error = false;
      heat_up_error = false;
      heater_pwm = 0;
      heaterPwmLoop();  // called to set PWM before exiting
      debugprintln("heating stopped");
      break;
    } 

    showHeat(heat_time_s);
    buzzerLoop();
    errorCheckLoop(heat_set_temp, heat_active);
    heaterPwmLoop();
    ledHeatDisplay(cur_temp, LED_BRIGHTNESS);
  }
}

/**
 * @brief Parameter menu control function
 */
void parameterMenu(){
  static int select_index = 0;

  while(1){
    buttons_state_t cur_button = getButtonsState();

    /** 
    * Parameter menu button control
    * 
    * UP/DN   scroll the menu
    * OK      select the highlighted option
    * UP+DN   exit
    */  
    switch(cur_button){
      case BUTTONS_UP_PRESS:  
        if(--select_index < 0){
          select_index = 0;
          buzzerBeep(SCROLL_LIMIT_BEEP);
        } else {
          buzzerBeep(SCROLL_BEEP);
        }
        break;
      case BUTTONS_DN_PRESS:
        if(++select_index >= PARAMETER_NUM_ITEMS){
          select_index = PARAMETER_NUM_ITEMS - 1;
          buzzerBeep(SCROLL_LIMIT_BEEP);
        } else {
          buzzerBeep(SCROLL_BEEP);
        }
        break;
      case BUTTONS_OK_PRESS:
        buzzerBeepBlocking(CLICK_BEEP);
        switch(select_index){
          case PARAMETER_PID:
            pidParameter();
            break;
          case PARAMETER_REFLOW:
            profileParameter();
            break;
          default:
            break;
        }
        break;
      default:
        break;
    }

    if(cur_button == BUTTONS_UPDN_PRESS){
      break;
    } 

    showParameterMenu(select_index);
    buzzerLoop();
  }

}

/**
 * @brief PID parameter menu control function
 * Menu to change PID parameters
 */
void pidParameter(){

  static int select_index = 0;
  static bool selected = false;
  
  while(1){
    buttons_state_t cur_button = getButtonsState();

    /** 
    * PID parameter menu button control
    * 
    * UP/DN   scroll through paramters, increase/decrease selected parameter
    * OK      select the highlighted option
    * UP+DN   exit
    */  
    switch(cur_button){
      case BUTTONS_UP_PRESS:
        if (selected){  // change parameter value if selected
          pid_items[select_index].val += PID_PARAMETER_STEP;
          updatePidParams(select_index);
        } else { // move to prev option otherwise
          if(--select_index < 0){
            select_index = 0;
            buzzerBeep(SCROLL_LIMIT_BEEP);
          } else {
            buzzerBeep(SCROLL_BEEP);
          }
        }
        break;
      case BUTTONS_DN_PRESS:
        if (selected){  // change parameter value if selected
          pid_items[select_index].val -= PID_PARAMETER_STEP;
          updatePidParams(select_index);
        } else {  // move to next option otherwise
          if(++select_index >= PID_NUM_ITEMS){
            select_index = PID_NUM_ITEMS - 1;
            buzzerBeep(SCROLL_LIMIT_BEEP);
          } else {
            buzzerBeep(SCROLL_BEEP);
          }
        }
        break;
      case BUTTONS_OK_PRESS:
        buzzerBeep(CLICK_BEEP);
        selected = !selected;
        break;
      default:
        break;
    }

    if(cur_button == BUTTONS_UPDN_PRESS){
      selected = false;
      break;
    } 

    showPidParameters(select_index, selected);
    buzzerLoop();
  }
}
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
void loop() { // never goes here
}

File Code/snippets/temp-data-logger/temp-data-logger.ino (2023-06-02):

/**
  * Temperature Data Logger
  * Author: Badar Jahangir Kayani
  * Email: badarjahangir@gmail.com
  * Date: 6/2/2023
  *
  * Reads themperature from the sensors, displays it on
  * the OLED display and sends it over the Serial port
  * 
  *   - ESP32-C3 Dev Board
  *   - 3x MAX6675 Thermocouple Module
  *   - 128x64 SSD1306 0.91" OLED Display
  *   - Optional MLX90614 IR temperature sensor 
  */

#include "MAX6675.h"
#include <Adafruit_MLX90614.h>
#include <Wire.h>
#include <Adafruit_GFX.h>
#include <Adafruit_SSD1306.h>

#define THRM_CPL_DATA 7
#define THRM_CPL_CLK  6
#define THRM_CPL_SEL1 4
#define THRM_CPL_SEL2 5
#define THRM_CPL_SEL3 0

#define SDA_PIN 2
#define SCL_PIN 3 
#define OLED_SCREEN_ADDRESS 0x3C 

MAX6675 thermoCouple1;
MAX6675 thermoCouple2;
MAX6675 thermoCouple3;
Adafruit_MLX90614 ir = Adafruit_MLX90614();
Adafruit_SSD1306 display(128, 64, &Wire, -1);

float thrm_cpl_temp_1 = 0.0;
float thrm_cpl_temp_2 = 0.0;
float thrm_cpl_temp_3 = 0.0;

void setup()
{
  Serial.begin(115200);

  // MAX6675 thermocouple init
  thermoCouple1.begin(THRM_CPL_CLK, THRM_CPL_SEL1, THRM_CPL_DATA);
  thermoCouple2.begin(THRM_CPL_CLK, THRM_CPL_SEL2, THRM_CPL_DATA);
  thermoCouple3.begin(THRM_CPL_CLK, THRM_CPL_SEL3, THRM_CPL_DATA);

  thermoCouple1.setSPIspeed(4000000);
  thermoCouple2.setSPIspeed(4000000);
  thermoCouple3.setSPIspeed(4000000);

  // ir.begin();

  // OLED display init
  Wire.begin(SDA_PIN, SCL_PIN);
  if(!display.begin(SSD1306_SWITCHCAPVCC, OLED_SCREEN_ADDRESS)) {
    Serial.println("OLED Display Init Failed");
  }
  display.clearDisplay();
}

void loop()
{
  readThrmCpl();

  printSerial();

  printDisplay();

  delay(1000);
}

void printDisplay(){
  display.clearDisplay();

  display.setTextSize(1);
  display.setTextColor(SSD1306_WHITE);
  
  display.setCursor(0,0);
  display.println(thrm_cpl_temp_1);

  display.setCursor(0,20);
  display.println(thrm_cpl_temp_2);

  display.setCursor(0,40);
  display.println(thrm_cpl_temp_3);

  display.display();
}

void printSerial(){
  Serial.print(thrm_cpl_temp_1);
  Serial.print(",");
  Serial.print(thrm_cpl_temp_2);
  Serial.print(",");
  Serial.print(thrm_cpl_temp_3);
  Serial.print(",");

  Serial.println("");
}

void readThrmCpl(){
  if(!thermoCouple1.read()){
    thrm_cpl_temp_1 = thermoCouple1.getTemperature();
  } else {
    thrm_cpl_temp_1 = -999;
  }

  if(!thermoCouple2.read()){
    thrm_cpl_temp_2 = thermoCouple2.getTemperature();
  } else {
    thrm_cpl_temp_2 = -999;
  }

  if(!thermoCouple3.read()){
    thrm_cpl_temp_3 = thermoCouple3.getTemperature();
  } else {
    thrm_cpl_temp_3 = -999;
  }
}

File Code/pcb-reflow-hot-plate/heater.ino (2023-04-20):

/**
 * PCB Reflow Hot Plate
 * heater.ino 
 * Heater PWM and PID step function
 * 
 * TODO: Add temperature discontinuity sensing
 */



/**
 * @brief Manage heater PWM 
 * This function needs to be run in a fast loop
 * Manual PWM implemented due to super slow requirement of the SSR
 */
void heaterPwmLoop(){
  static unsigned long last_on_time = 0;
  static unsigned long last_off_time = 0;
  static bool heater_pwm_on = false;
  static int on_time = 0;
  static int off_time = 0;

  heater_pwm = constrain(heater_pwm, 0, PWM_MAX);

  // Calculate on time and off time for given duty cycle
  on_time = ( PWM_PERIOD * heater_pwm ) / PWM_MAX;
  off_time = ( PWM_PERIOD * (PWM_MAX - heater_pwm) ) / PWM_MAX;

  if(heat_active || reflow_active){

    if(heater_pwm == PWM_MAX){ // Full on for 100% duty cycle
      digitalWrite(SSR_PIN, HIGH);
      heater_pwm_on = true;
      last_on_time = millis();
    } else if(heater_pwm == 0){ // Full off for 0% duty cycle
      digitalWrite(SSR_PIN, LOW);
      heater_pwm_on = false;
      last_off_time = millis();

    // On period has completed, switch to off period
    } else if(heater_pwm_on && (millis() - last_on_time) > on_time){
      heater_pwm_on = false;
      last_off_time = millis();
      digitalWrite(SSR_PIN, LOW);

    // Off period has completed, switch to on period
    } else if (!heater_pwm_on && (millis() - last_off_time) > off_time){
      heater_pwm_on = true;
      last_on_time = millis();
      digitalWrite(SSR_PIN, HIGH);
    }  
  } else {
    // Turn off if heat and reflow modes are both inactive
    digitalWrite(SSR_PIN, LOW);
  }
}


/**
 * @brief PID Step function for heater PWM
 * This functions needs to be called in a loop
 * It will calculate next PWM value using PID control
 * PID calculation is done at PID_STEP_INTERVAL gaps
 * @param set_temp target temperature
 * @param mode reflow or heat mode
 * @return int PWM value from PID algorithm
 * 
 * TODO: Check the delta_t used for calculation to be accurate
 */
int pidStep(float set_temp, int mode){
  // Time tracking variables
  static unsigned long last_time = 0;
  static unsigned long last_deriv_time = 0;
  static unsigned long cur_time = 0;
  static unsigned long delta_time_ms = 0;
  static unsigned long delta_deriv_time_ms = 0;
  static float delta_time_s = 0.0;
  static float delta_deriv_time_s = 0.0;
  // PID calculation variables
  static float Kp = 0.0;
  static float Ki = 0.0;
  static float Kd = 0.0;
  static float temp_error = 0.0;
  static float prev_error = 0.0;
  static float prop = 0.0;
  static float integ = 0.0;
  static float deriv = 0.0;
  static float pid_output = 0.0;
  // Moving averaging filter variables
  static float pid_output_smooth = 0.0;
  static int pid_output_array[PID_FILTER_SIZE];
  static int ind = 0;
  static float sum = 0.0;

  static int heater_check_last_temp = 0;

  // Update PID parameters from struct based on selected mode
  if(mode == HEAT){
    Kp = pid_items[PID_KP].val;
    Ki = pid_items[PID_KI].val;
    Kd = pid_items[PID_KD].val;
  } else if (mode == REFLOW){
    Kp = pid_items[PID_KP_R].val;
    Ki = pid_items[PID_KI_R].val;
    Kd = pid_items[PID_KD_R].val;
  }
  
  // Calculate the time gap between now and the last step
  cur_time = millis();
  delta_time_ms = cur_time - last_time;

  // Reset the calculation if function called after long delay
  if(delta_time_ms > (2 * PID_STEP_INTERVAL)){
    debugprintln("pid reset");

    // Reset tracking variables
    temp_error = 0;
    prev_error = 0;
    prop = 0;
    integ = 0;
    deriv = 0;
    pid_output = 0;
    
    sum = 0;
    // Prepopulate the moving filter array for instant ramp
    pid_output = constrain((Kp * (set_temp - cur_temp)), 0, PWM_MAX); // use proportional error only
    for(int i = 0; i < PID_FILTER_SIZE; i++){
      pid_output_array[i] = pid_output; // populate the array
      sum += pid_output; // add up the sum
    }
    ind = 0;
    pid_output_smooth = pid_output;
    last_time = cur_time;

  // Run PID calculation every PID_STEP_INTERVAL
  } else if(delta_time_ms > PID_STEP_INTERVAL){

    delta_time_s = (float)delta_time_ms / 1000.0; // time since last cal in seconds (float)

    temp_error = set_temp - cur_temp; // proportional error
    prop = temp_error;

    // Only calculate integral when proportional is within a certain range to avoid windup
    if(pid_output < INTEG_ACTIVE_THRESH && pid_output > 0){
      integ = integ + (temp_error * delta_time_s);
    } else {
      integ = 0;
    }
    
    // Calculate time since last derivative calculation
    delta_deriv_time_ms = cur_time - last_deriv_time;
    delta_deriv_time_s = (float)delta_deriv_time_ms / 1000.0;

    // Calculate derivative every DERIV_CALC_INTERVAL
    if(delta_deriv_time_ms > DERIV_CALC_INTERVAL){
      deriv = (temp_error - prev_error) / delta_deriv_time_s;
      last_deriv_time = cur_time;
      prev_error = temp_error;
    }
    
    // Add up all elements for output
    pid_output = (Kp * prop) + (Ki * integ) + (Kd * deriv * PID_KD_PREGAIN);
    pid_output = constrain(pid_output, 0, PWM_MAX);

    // Moving average filter step calculation
    sum -=  pid_output_array[ind];
    pid_output_array[ind] = (int)pid_output;
    sum += (int)pid_output;
    ind = (ind + 1) % PID_FILTER_SIZE;
    pid_output_smooth = sum / PID_FILTER_SIZE;

    last_time = cur_time;
    
    debugprint(set_temp);
    debugprint(",");
    debugprint(cur_temp);
    debugprint(",");
    // debugprint(pid_output);
    // debugprint(",");
    debugprint(pid_output_smooth);
    // debugprint(",");
    // debugprint(prop);
    // debugprint(",");
    // debugprint(integ);
    // debugprint(",");
    // debugprintln(deriv);
    debugprint("\n");
  }

  pid_output_smooth = constrain(pid_output_smooth, 0, PWM_MAX);
  pid_output_smooth = round(pid_output_smooth);

  return pid_output_smooth;
}

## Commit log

2023-04-12 initial commit (code, cad)
    [Housing Base v5.STL, Housing Base.SLDPRT, Housing Top v1.STL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]
2023-04-14 Rev 1.1 PCB, housing update
    [Housing Base v6.STL, Housing Base v7.STL, Housing Base.SLDPRT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]
2023-04-14 more test data, logger code, reorg
    [top-center_top-edge_diff.csv, top-up_top-down_diff.csv, top_bottom.csv]
2023-04-16 cad update, readme update
    [97654A673_18-8 Stainless Steel Flanged Button Head Screw.SLDPRT, Housing Base.SLDPRT, Housing Top v2.STL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]
2023-04-16 more test data, readme updated
    [pcb-reflow-hot-plate.kicad_sch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]
2023-04-18 buzzer sequence added, readme updated
    [Housing Top v4.STL, PCB Reflow Hot Plate Assembly.SLDASM, hot-plate-120x70-assembly.SLDASM]
2023-04-20 safety features, bug fix, housing update
    [Housing Top v5.STL, Housing Top.SLDPRT, PCB Reflow Hot Plate Assembly.SLDASM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]
2023-04-26 housing design update
    [Housing Base.SLDPRT, Housing Top v6.STL, Housing Top.SLDPRT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]
2023-04-27 PCB Rev 1.2
    [pcb-reflow-hot-plate.kicad_pcb, pcb-reflow-hot-plate.kicad_sch]
2023-06-02 new cad
    [Housing Base v8.STL, Housing Base.SLDPRT, Housing Top v7-n.STL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]
2023-06-02 restore stash with led start
    [Housing Top v7.STL, Housing Top v8.STL, Housing Top v9.STL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]
2023-06-02 CAD cleanup
    [Housing Base Rev1.0 Rev1.1.STL, Housing Base v5.STL, Housing Base v6.STL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]
2023-09-24 rgb status led added
2023-09-24 cad cleanup and update
    [Housing Base Rev1.0 Rev1.1.STL, Housing Base v1.STL, Housing Base v2.STL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]
2023-09-24 pcb rev 1.3
    [pcb-reflow-hot-plate.kicad_pcb, pcb-reflow-hot-plate.kicad_sch]
2024-01-04 housing top cad update
    [Housing Top v3-1.STL, Housing Top.SLDPRT]

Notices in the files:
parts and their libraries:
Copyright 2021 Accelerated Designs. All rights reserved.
